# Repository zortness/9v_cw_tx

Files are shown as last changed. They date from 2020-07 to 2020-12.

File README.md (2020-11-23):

# 9V QRP Micro Transciever

Based on the schematic and work of Jeff Anderson, [K6JCA](https://www.qrz.com/db/k6jca)
and [this blog post](http://k6jca.blogspot.com/2009/08/9v-qrp-transceiver.html).

Thank you to Jeff for your help in debugging my implementation of your design.

## About

This is a very simple, direct conversion CW transciever that will operate on the 40m 
amateur radio band. It requires an external speaker or headphones, an external antenna,
and an external keyer for sending. 

This design is intended to allow modifying the center frequency of the transciever by
changing out the oscillator crystal without re-soldering any parts. 

**This is still a work in progress.**

I have devided up the functionality across two small PCBs and used a 8-pin jumper between them.
This gives a bit more room to spread out the components, and hopefully avoid unwanted interactions.
It should also give a bit larger ground plane, which should help with environmental sensitivity.

The transmitter has an observed harmonic transmission on 14m, which might necessitate an external 
band pass filter board at some point.

The power output in my experiements so far has been quite small, in the 50-100mW range. 

The effective receive and transmit frequencies can also be apart from one another by enough that
you may not hear someone responding directly on your transmit frequency. This seems to be worse
at either extreme of the VXO adjustment, but not verified by data yet.

## Schematics

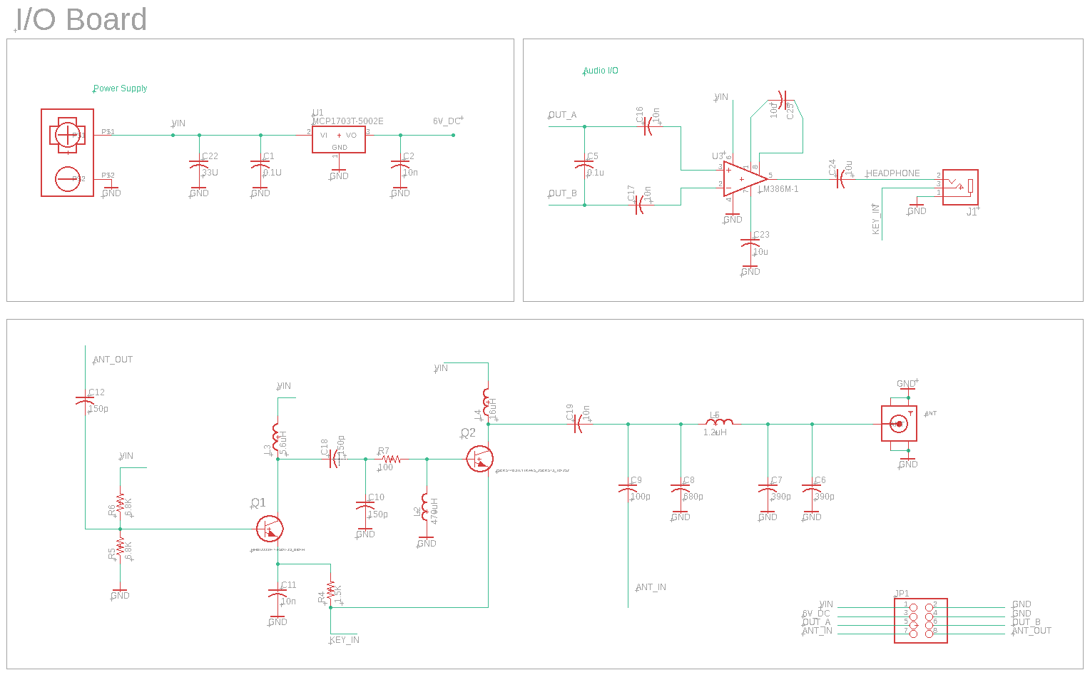
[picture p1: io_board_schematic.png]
IO board schematic


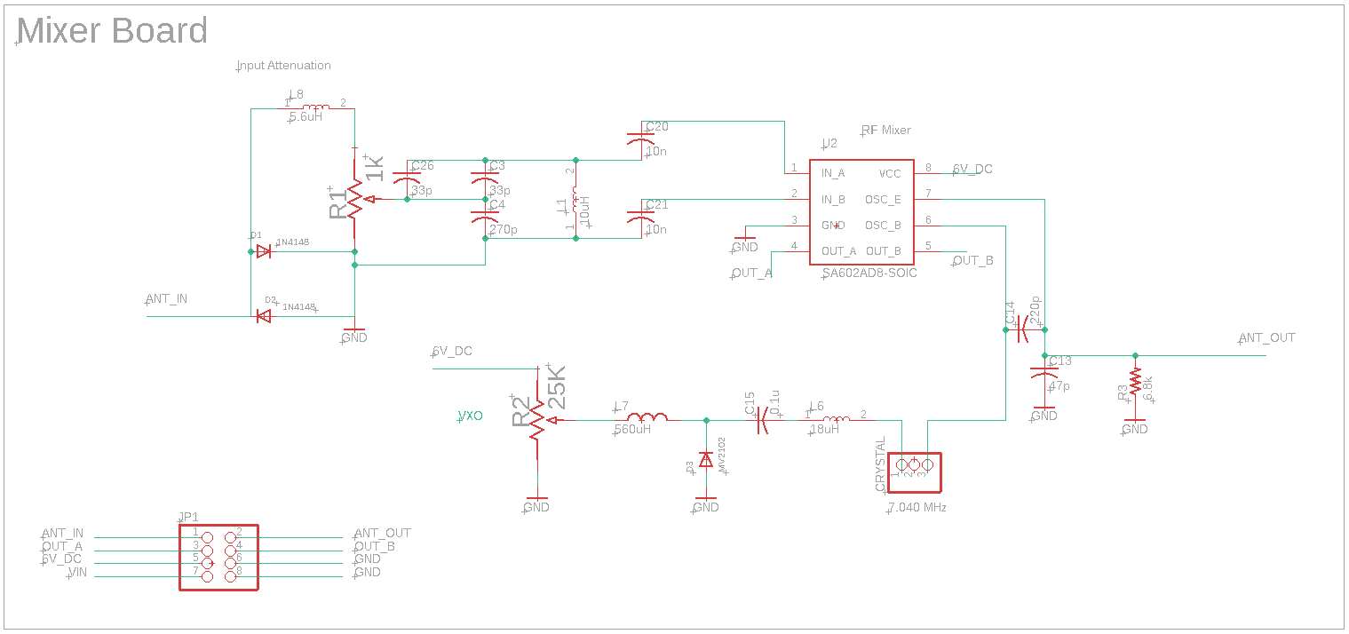
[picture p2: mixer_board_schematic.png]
Mixer board schematic


## Board Layouts

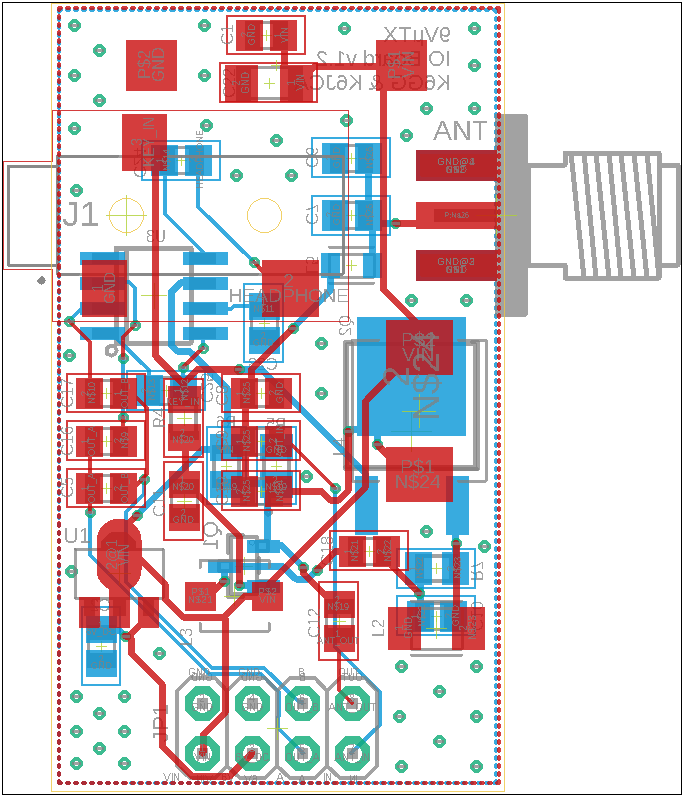
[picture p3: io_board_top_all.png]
IO board layout


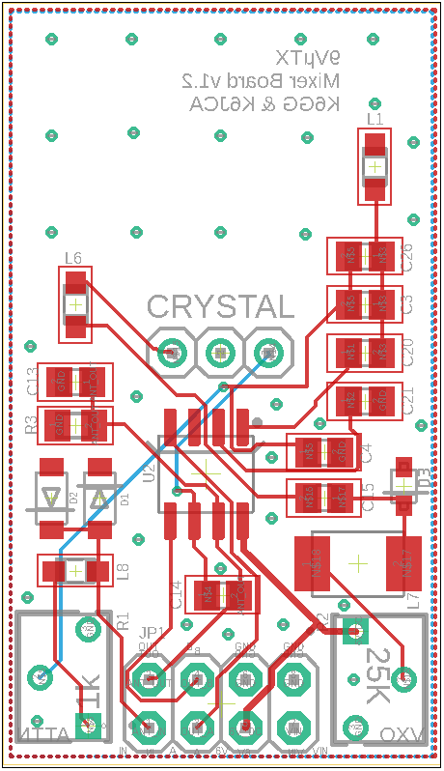
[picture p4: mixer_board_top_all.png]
Mixer board layout


## ProtoBoard Prototype 

This prototype is extremely sensitive to capacitance (even touch), and lacks a true ground plane,
though I added through-hole-pins to act as grounding feet on my steel work table. 

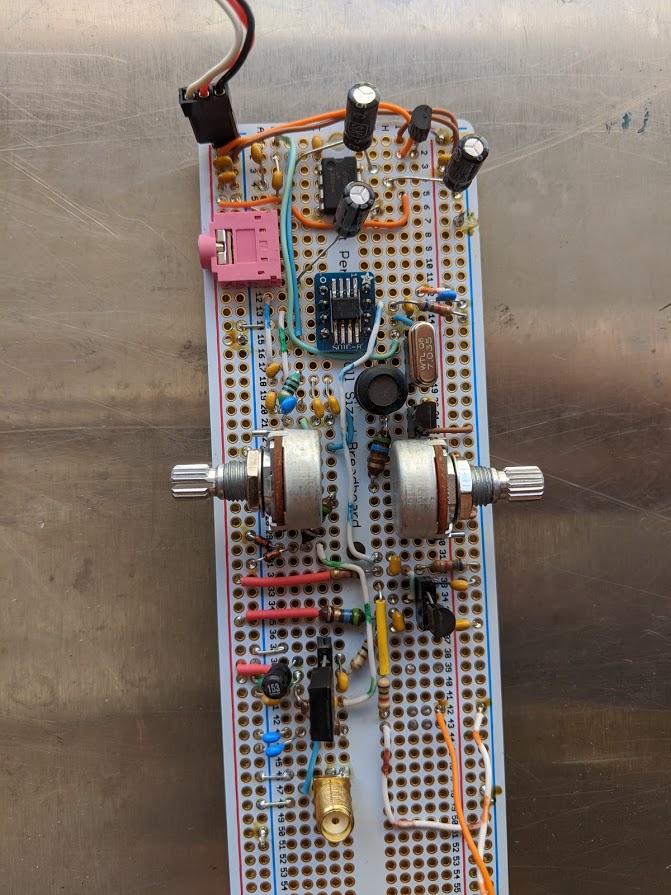
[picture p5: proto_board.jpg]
proto board


## SMD Prototypes

I've gone through a few SMD prototypes and made a number of pad and routing mistakes. I also chose
a number of parts poorly or just completely misread the units on the part values (nH != uH, pF != uF). 

I will update when one of the boards can operate without any further modification.

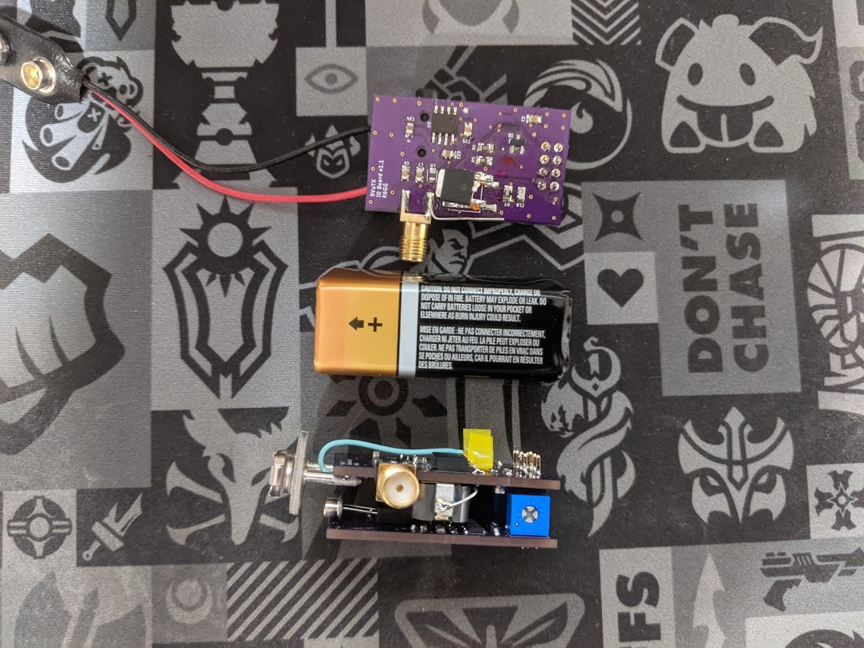
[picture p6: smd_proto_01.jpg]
proto board

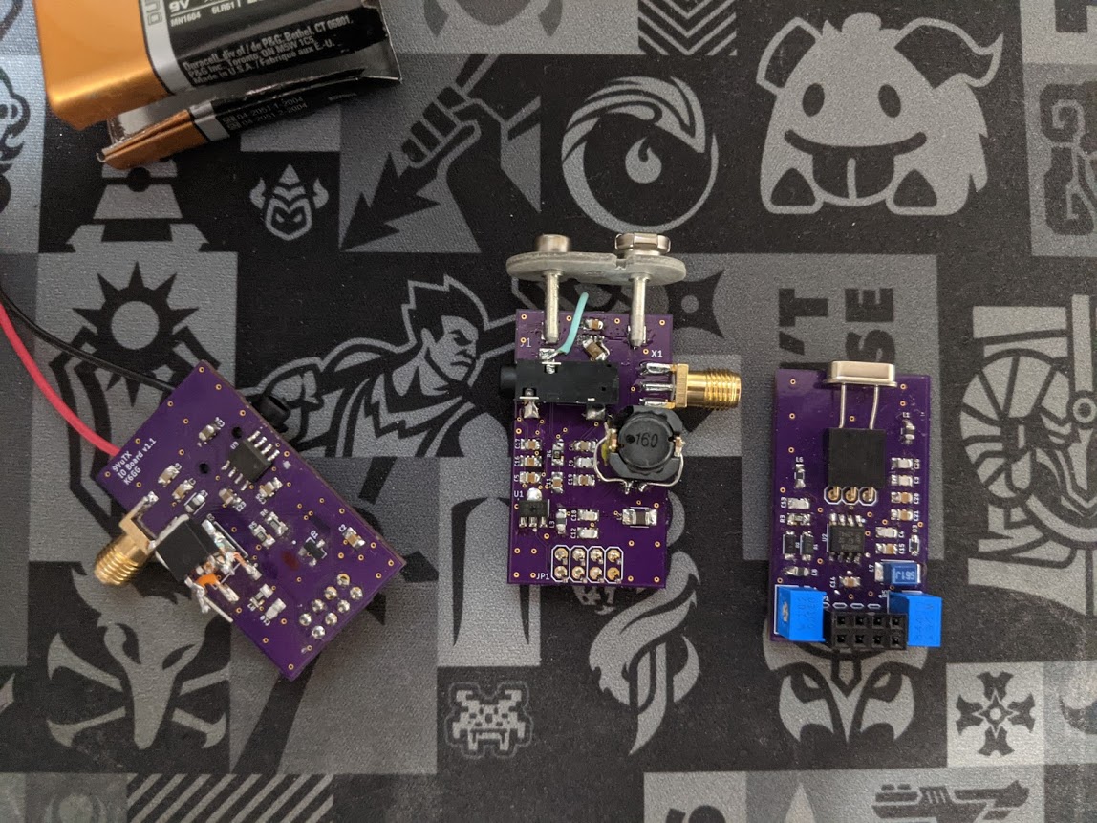
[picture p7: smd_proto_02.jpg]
proto board

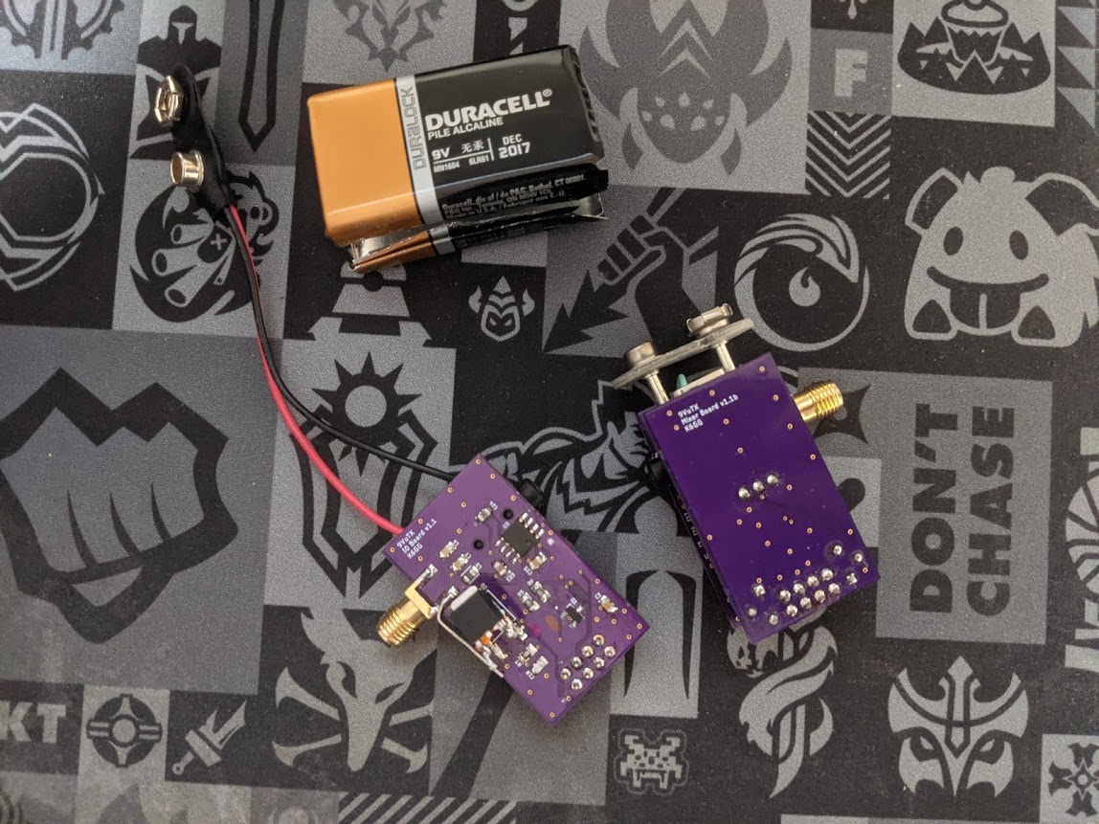
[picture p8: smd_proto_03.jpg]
proto board

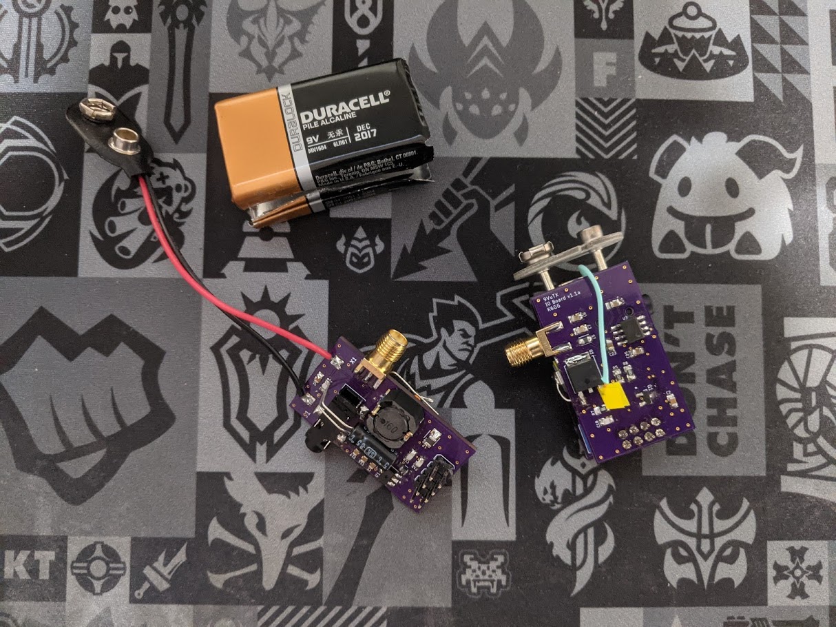
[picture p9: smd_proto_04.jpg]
proto board


## SMD BOM
|Manufacturer Part Number|Manufacturer |Digi-Key Part Number |Customer Reference |Reference Designator |Part Status|Quantity|Unit Price|Extended Price|
|---|---|---|---|---|---|---|---|---|
|MCP1703T-5002E/MB |Microchip Technology |MCP1703T-5002E/MBCT-ND |[U1] 5V regulator |U1 |Active |1 |0.54 |$0.54 |
|SA602AD/01,118 |NXP USA Inc. |568-1200-1-ND |[U2] RF Mixer |U2 |Active |1 |2.88 |$2.88 |
|LM386MX-1/NOPB |Texas Instruments |LM386MX-1/NOPBCT-ND |[U3] Audio Amp |U3 |Active |1 |1.02 |$1.02 |
|1N4148W-7-F |Diodes Incorporated |1N4148W-FDICT-ND |[D1,2] diode |D1, D2 |Active |2 |0.16 |$0.32 |
|1SV281(TPH3,F) |Toshiba Semiconductor and Storage|1SV281(TPH3F)CT-ND |[D3] varicap diode |D3 |Active |1 |0.36 |$0.36 |
|LBR2012T100K |Taiyo Yuden |587-2045-1-ND |[L1] inductor 10uH |L1 |Active |1 |0.13 |$0.13 |
|CB2518T471K |Taiyo Yuden |587-2194-1-ND |[L2] inductor 470uH |L2 |Active |1 |0.17 |$0.17 |
|MLF2012E5R6KT000 |TDK Corporation |445-1056-1-ND |[L8] inductor 5.6uH |L8 |Active |1 |0.18 |$0.18 |
|#B966AS-160M=P3 |Murata Electronics |490-14125-1-ND |[L4] inductor 16uH |L4 |Active |1 |0.95 |$0.95 |
|MLF2012A1R2JT000 |TDK Corporation |445-181331-1-ND |[L5] inductor 1.2uH |L5 |Active |1 |0.22 |$0.22 |
|MLF1608C180KTA00 |TDK Corporation |445-1028-1-ND |[L6] inductor 18uH |L6 |Active |1 |0.17 |$0.17 |
|NL453232T-561J-PF |TDK Corporation |445-NL453232T-561J-PFCT-ND|[L7] inductor 560uH |L7 |Active |1 |0.43 |$0.43 |
|3362W-1-102LF |Bourns Inc. |3362W-102LF-ND |[R1] potentiometer 1k |R1 |Active |1 |1.02 |$1.02 |
|3362W-1-253LF |Bourns Inc. |3362W-253LF-ND |[R2] potentiometer 25k |R2 |Active |1 |1.02 |$1.02 |
|CRG0805F6K8 |TE Connectivity Passive Product  |A126384CT-ND |[R3,5,6] resistor 6.8k |R3, R5, R6 |Active |3 |0.1 |$0.30 |
|CRGCQ0805F1K5 |TE Connectivity Passive Product  |A129751CT-ND |[R4] resistor 1.5k |R4 |Active |1 |0.1 |$0.10 |
|2SCR574D3TL1 |Rohm Semiconductor |2SCR574D3TL1CT-ND |[Q2] NPN transistor 2A |Q2 |Active |1 |0.82 |$0.82 |
|SJ-3502-SMT-TR |CUI Devices |CP-3502SJCT-ND |[J1] Audio Jack |J1 |Active |1 |1.22 |$1.22 |
|CON-SMA-EDGE-S |RF Solutions |CON-SMA-EDGE-S-ND |[J2] SMA-F edge connector |J2 |Active |1 |1.69 |$1.69 |
|PH2-20-UA |Adam Tech |2057-PH2-20-UA-ND |[JP1] Jumper Pins Male |JP1 |Active |1 |0.26 |$0.26 |
|PPPC042LFBN-RC |Sullins Connector Solutions |S7107-ND |[JP2] 8-pin Jumper Female |JP2 |Active |1 |0.69 |$0.69 |
|PPPC031LGBN-RC |Sullins Connector Solutions |S5478-ND |[J3] 3-pin Female Crystal Socket|J3 |Active |1 |0.51 |$0.51 |
|968 |Keystone Electronics |36-968-ND |[B1] 9V battery connector |B1 |Active |1 |1.48 |$1.48 |
|C0805C104Z5VACTU |KEMET |399-1177-1-ND |[C1,5,15] capacitor 0.1uF |C1, C5, C15 |Active |3 |0.1 |$0.30 |
|C0805C330K5GACTU |KEMET |399-8062-1-ND |[C3,22,26] capacitor 33pF |C3, C22, C26 |Active |3 |0.11 |$0.33 |
|CC0805JRNPO9BN271 |Yageo |311-1116-1-ND |[C4] capacitor 270pF |C4 |Active |1 |0.13 |$0.13 |
|CC0805KRX7R9BB391 |Yageo |311-1193-1-ND |[C6,7] capacitor 390pF |C6, C7 |Active |2 |0.12 |$0.24 |
|CC0805KRX7R9BB681 |Yageo |311-1126-1-ND |[C8] capacitor 680pF |C8 |Active |1 |0.11 |$0.11 |
|C0805C101JAGAC7800 |KEMET |399-15000-1-ND |[C9] capacitor 100pF |C9 |Active |1 |0.1 |$0.10 |
|C0805C151J5GACTU |KEMET |399-1125-1-ND |[C10,12,18] capacitor 150pF |C10, C12, C18 |Active |3 |0.1 |$0.30 |
|C0805C470K5GACTU |KEMET |399-8081-1-ND |[C13] capacitor 47pF |C13 |Active |1 |0.11 |$0.11 |
|C0805C221M5RACTU |KEMET |399-8039-1-ND |[C14] capacitor 220pF |C14 |Active |1 |0.1 |$0.10 |
|RC0805FR-07100RL |Yageo |311-100CRCT-ND |[R7] resistor 100 Ohm |R7 |Active |3 |0.1 |$0.30 |
|MMBT2222A-7-F |Diodes Incorporated |MMBT2222A-FDICT-ND |[Q1] NPN Transistor .6A |Q1 |Active |1 |0.13 |$0.13 |
|SJ-3523-SMT-TR |CUI Devices |CP-3523SJCT-ND |[J1] 3.5mm Stereo Phone Jack |J1 |Active |1 |0.93 |$0.93 |
|GRM21BR61E106KA73K |Murata Electronics |490-16824-1-ND |[C23,24,25] capacitor 10uF |C23, C24, C25 |Active |3 |0.23 |$0.69 |
|C3216X5R1C336M160AB |TDK Corporation |445-6002-1-ND |[C22] capacitor 33pF |C22 |Active |1 |1.03 |$1.03 |
|CL21B103KBANNNC |Samsung Electro-Mechanics |1276-1015-1-ND |[C2,11,16,17,19,20,21] capacitor 10nF|C2, C11, C16, C17, C19, C20, C21|Active |10 |0.045 |$0.45 |
|ASPI-0630LR-150M-T15 |Abracon LLC |ASPI-0630LR-150M-T15CT-ND |[L4] Inductor 15uH |L4 |Active |1 |0.87 |$0.87 |
|SRP3012C-5R6M |Bourns Inc. |118-SRP3012C-5R6MCT-ND |[L3] Inductor 5.6uH | |Active |1 |0.96 |$0.96 |

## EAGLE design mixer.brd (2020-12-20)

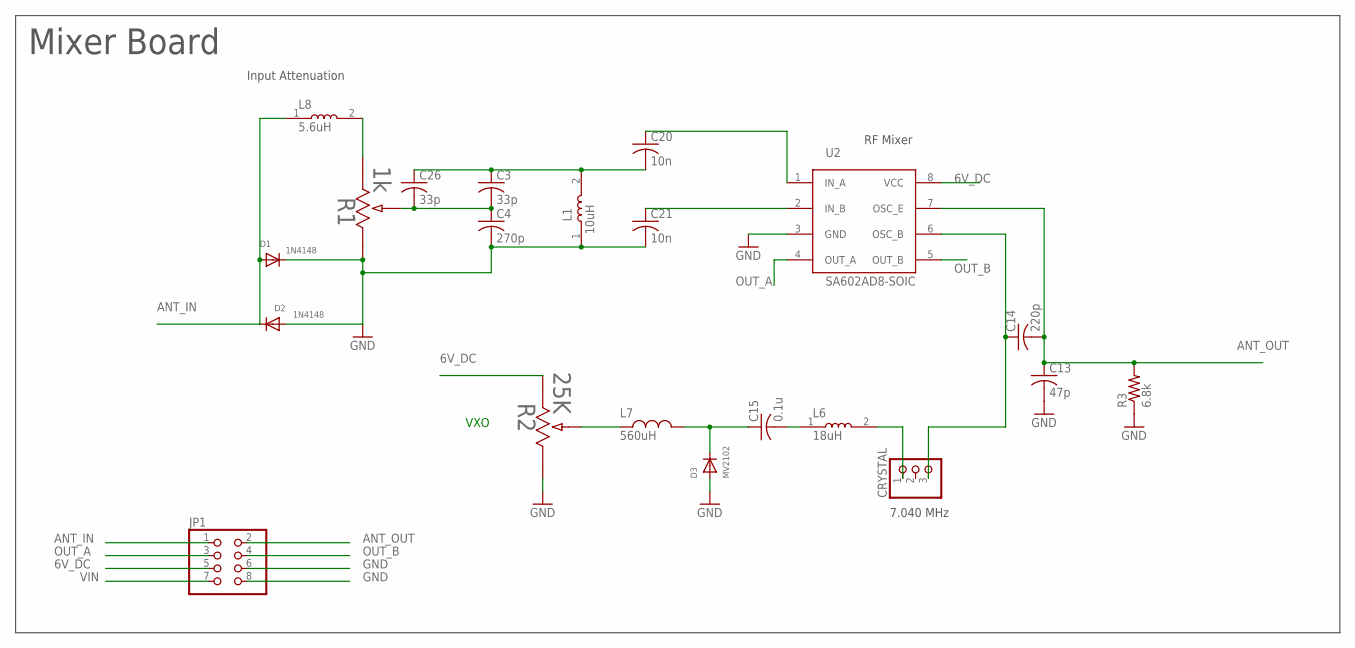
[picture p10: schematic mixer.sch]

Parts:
C3, C26: 33p; C0805
C4: 270p; C0805
C13: 47p; C0805
C14: 220p; C0805
C15: 0.1u; C0805
C20, C21: 10n; C0805
CRYSTAL: PINHD-1X3; 1X03
D1, D2: 1N4148; SOD-123FL
D3: MV2102; SOD-323F
JP1: PINHD-2X4; 2X04
L1: 10uH; INDC2012X87N
L6: 18uH; INDC2012X87N
L7: 560uH; INDM4532X32_W
L8: 5.6uH; INDC2012X87N
R1: 1k; POT_3362W
R2: 25K; POT_3362W
R3: 6.8k; M0805
U2: SA602AD8-SOIC; SOIC127P599X175-8N

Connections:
6V_DC: JP1.5, R2.1, U2.8 (VCC)
ANT_IN: D1.A, D2.C, JP1.1, L8.1
ANT_OUT: C13.1, C14.2, JP1.2, R3.2, U2.7 (OSC_E)
GND: C4.2, C13.2, C21.2, D1.C, D2.A, D3.A, JP1.6, JP1.8, L1.1, R1.3, R2.3, R3.1, U2.3 (GND)
unnamed: C20.1, U2.1 (IN_A)
unnamed: C21.1, U2.2 (IN_B)
unnamed: C3.1, C20.2, C26.1, L1.2
unnamed: C14.1, CRYSTAL.3, U2.6 (OSC_B)
unnamed: C3.2, C4.1, C26.2, R1.2
unnamed: L8.2, R1.1
unnamed: CRYSTAL.1, L6.2
unnamed: C15.2, L6.1
unnamed: C15.1, D3.C, L7.2
unnamed: L7.1, R2.2
OUT_A: JP1.3, U2.4 (OUT_A)
OUT_B: JP1.4, U2.5 (OUT_B)
VIN: JP1.7

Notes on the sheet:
Input Attenuation
RF Mixer
VXO
7.040 MHz
Mixer Board

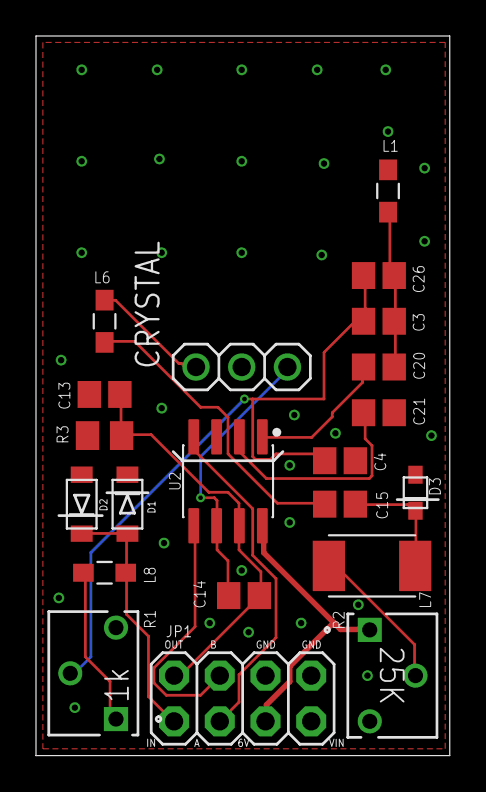
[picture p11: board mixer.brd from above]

Board: 2 copper layers, 23.0 x 40.0 mm, 21 parts (0 on the bottom side), 16 nets.

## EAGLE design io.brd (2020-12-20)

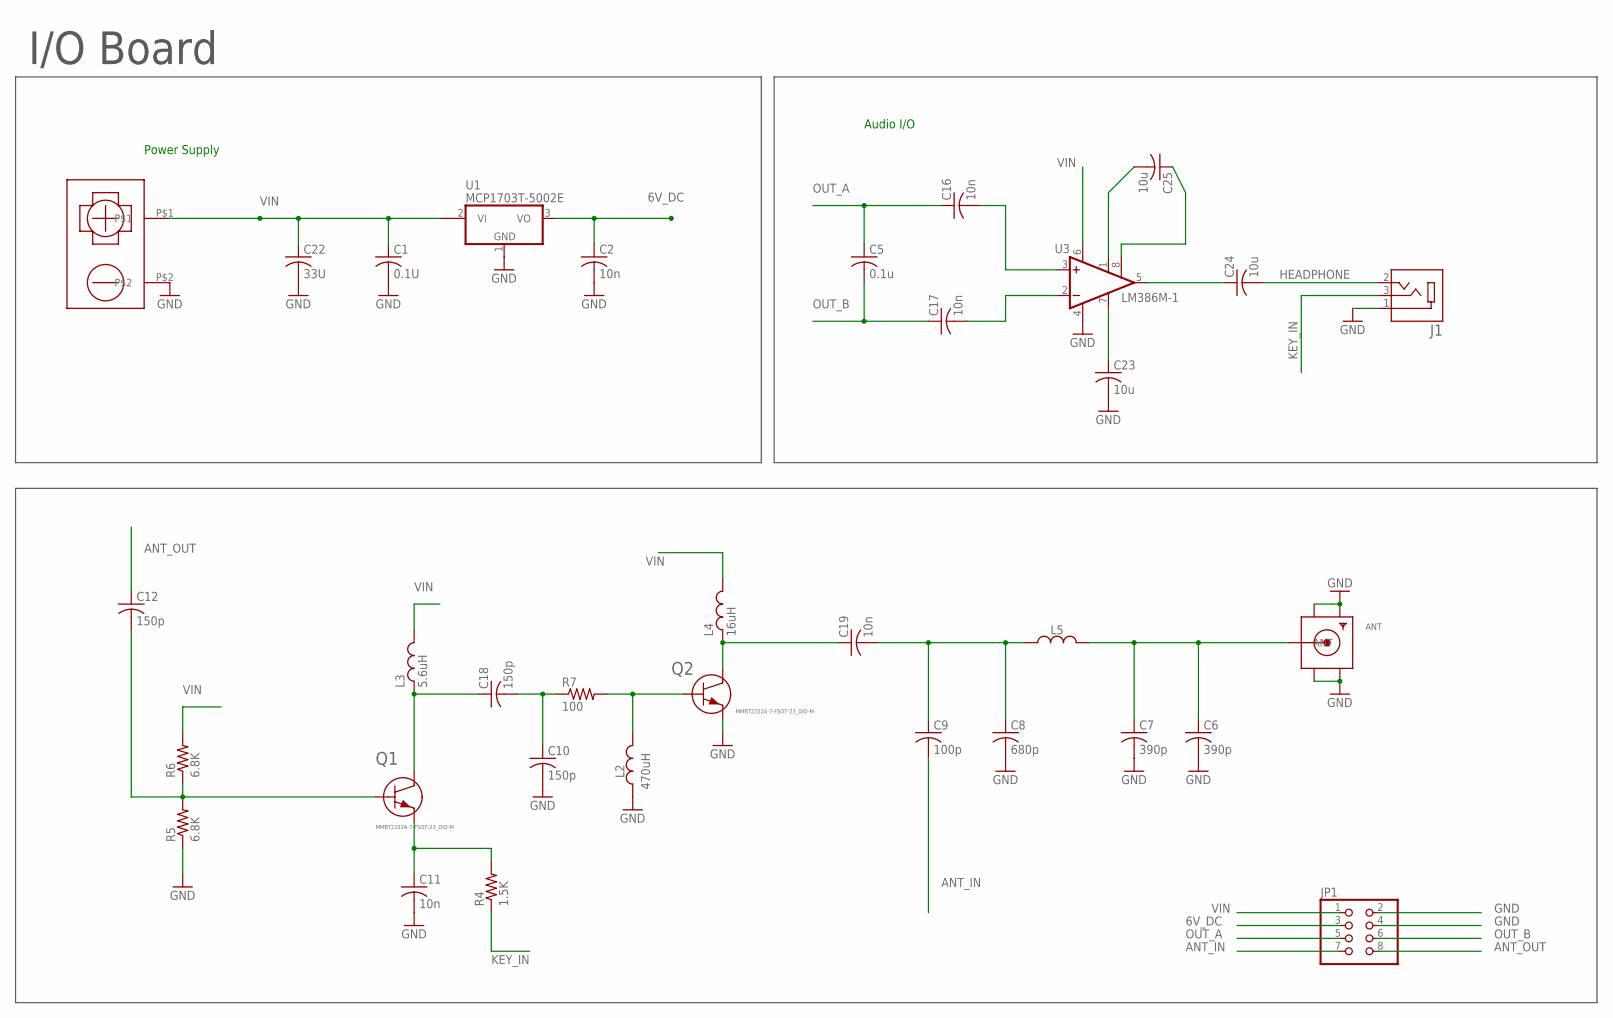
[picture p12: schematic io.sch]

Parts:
ANT: SMACONNECTOR_EDGE; SMA_EDGELAUNCH
C1: 0.1U; C0805
C2, C11, C16, C17: 10n; C0805
C5: 0.1u; C0805
C6, C7: 390p; C0805
C8: 680p; C0805
C9: 100p; C0805
C10, C12, C18: 150p; C0805
C19: 10n; C1206
C22: 33U; C1206
C23, C24, C25: 10u; C0805
J1: SJ-3523-SMT-TR; CUI_SJ-3523-SMT-TR
JP1: PINHD-2X4; 2X04
L2: 470uH; INDC2520X120N
L3: 5.6uH; SRP3012C
L4: 16uH; ASPI-0630LR
L5: 1.2uH; SRN4018TA
Q1, Q2: MMBT2222A-7-FSOT-23_DIO-M; SOT-23_DIO-M
R4: 1.5K; M0805
R5, R6: 6.8K; M0805
R7: 100; M0805
U1: MCP1703T-5002E; SOT89
U3: LM386M-1; SO08
U$1: 9V_9689V_968_SMD; 9V_968_PAD

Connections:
6V_DC: C2.1, JP1.3, U1.3 (VO)
ANT_IN: C9.2, JP1.7
ANT_OUT: C12.1, JP1.8
GND: ANT.GND@1 (GND4), ANT.GND@3 (GND2), C1.2, C2.2, C6.2, C7.2, C8.2, C10.2, C11.2, C22.2, C23.2, J1.1, JP1.2, JP1.4, L2.1, R5.1, U1.1 (GND), U3.4 (GND), U$1.P$2
HEADPHONE: C24.2, J1.2
KEY_IN: J1.3, R4.1
unnamed: C16.2, U3.3 (+IN)
unnamed: C17.2, U3.2 (-IN)
unnamed: C23.1, U3.7 (BYPASS)
unnamed: C25.1, U3.8 (GAIN)
unnamed: C25.2, U3.1 (GAIN)
unnamed: C24.1, U3.5 (OUT)
unnamed: C12.2, Q1.1, R5.2, R6.1
unnamed: C11.1, Q1.2 (3), R4.2
unnamed: C18.1, L3.P$1 (1), Q1.3 (2)
unnamed: C10.1, C18.2, R7.1
unnamed: L2.2, Q2.1, R7.2
unnamed: C19.1, L4.P$1 (1), Q2.3 (2)
unnamed: C8.1, C9.1, C19.2, L5.P$1 (1)
unnamed: ANT.P (ANT), C6.1, C7.1, L5.P$2 (2)
OUT_A: C5.1, C16.1, JP1.5
OUT_B: C5.2, C17.1, JP1.6
VIN: C1.1, C22.1, JP1.1, L3.P$2 (2), L4.P$2 (2), R6.2, U1.2@1 (VI1), U3.6 (VS), U$1.P$1

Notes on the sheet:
Power Supply
Audio I/O
I/O Board

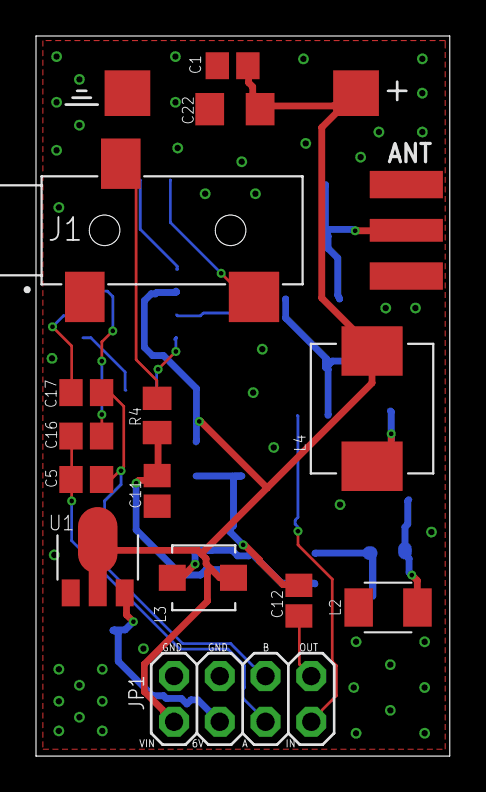
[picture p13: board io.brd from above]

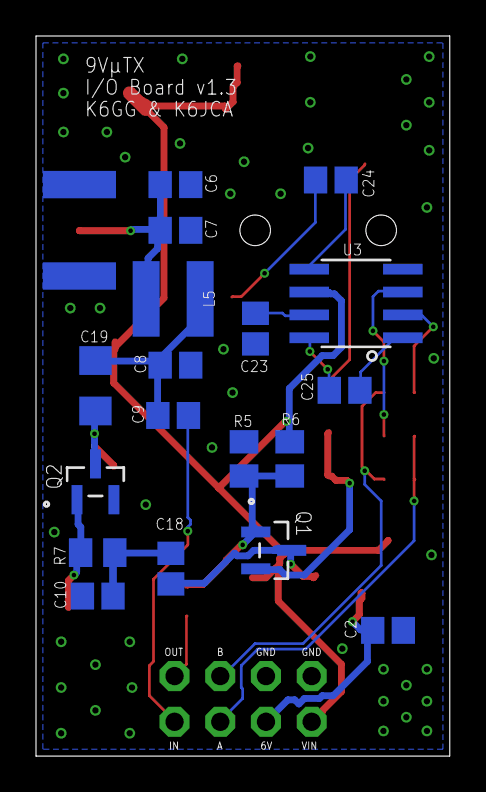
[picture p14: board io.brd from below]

Board: 2 copper layers, 23.0 x 40.0 mm, 34 parts (18 on the bottom side), 23 nets.

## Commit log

2020-05-26 initial commit
    An initial copy of K6JCA's CW transciever packaged in a 9V battery
    [main.brd, main.sch]
2020-05-27 first attempt at board layout
    [main.brd, main.sch]
2020-05-31 splitting boards, doing layouts
    Split into two boards with jumpers between. Added jumper for crystal to be able to change reference frequency. Closer to real layouts, still need to solidify some parts.
    [io.brd, io.sch, main.brd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]
2020-06-02 updating layouts and parts
    [io.brd, main.brd, mixer.brd]
2020-07-18 updated Q1, added readme
    Updated Q1 to be a better replacement for the original PN2222A in an SMD format. Also added a readme, with links to PNGs of the schematics and layout renderings, as well as a photo of one of my prototypes.
    [io.brd, io.sch]
2020-07-18 forgot to save mixer schematic
    Forgot to save while adjusting the schematic layout to make it more readable
    [mixer.sch]
2020-07-25 cleaned up boards, new screenshots
    Cleaned up the orientation and text on the boards. Ran them through the OshPark rules, and sent off v1 to get printed
    [io.brd, io.sch, mixer.brd]
2020-08-14 Updated boarts to v1.1
    9VuTX Version 1.1
    Several adjustments after mockup with V 1.0 of the board. That first version would be non-functional due to a few layout mismatches.
    * fixed 2nd transistor layout to actually match part / spec (TO-252)
    * rotated potentiometers 180 degrees so they face outward instead toward the middle of the board
    * expanded pads of L2 (450uH inductor) to match recommended spec
    * replaced phone jack with a true surface mount version (SJ-3523-SMT-TR)
    * re-arranged the IO board to allow for the different phone jack
    [io.brd, io.sch, mixer.brd]
2020-08-14 continuing on v 1.1
    * removed "label" label from SMA connector
    * increased the width of some lines likely to carry higher current
    * attempted to clean up some little stuff
    * updated images
    [io.brd, io.sch, main.brd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]
2020-08-18 Mixer board to 1.1a
    Realized the jumper on the Mixer board was not oriented correctly. Unfortunately already ordered some of the previous version, so this is a new version.
    [mixer.brd]
2020-08-18 Moving Mixer JP1 label
    [mixer.brd]
2020-09-01 Mixer board 1.1b
    * fixed pad size for L7
    [mixer.brd, mixer.sch]
2020-10-11 v1.1a of I/O board
    * Q2 pinout was wrong, pins 2 and 3 were swapped
    [io.brd, io.sch]
2020-10-16 Working on 1.1a of I/O after testing
    * replaced L4 with a much smaller component
    [io.brd, io.sch]
2020-10-17 Continuing on V1.1a of the I/O board
    * re-placed Q1 on the layout
    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
    [io.brd, io.sch, mixer.sch]
2020-10-17 Some cleanup
    * mixer board had incorrect Resistor labels
    * updated schematic PNG
    [mixer.brd, mixer.sch]
2020-11-21 v1.2 boards
    * corrected C22 as a 33uF (vs 33pF) capacitor with a 1206 footprint
    * Q2 emitter is now tied to Q1 emitter and KEY_IN to cut down on self resonance
    * Unused pin 4 on JP1 now tied to GND
    * All pins on JP1 labelled on top and bottom of each board
    * lots more GND vias
    [io.brd, io.sch, mixer.brd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]
2020-11-23 v1.2 updated inductors
    * updated L3 to a 650mA capable 5.6uH flat package
    * updated L4 to a 3A capable 15uH flat package... 16uH are difficult to come by
    * general board cleanup for readability
    [io.brd, io.sch, mixer.brd]
2020-11-23 Image updates
    * new boards and schematics
    * new photos of smd prototypes
2020-11-23 Update README to contain BOM
    Added a Bill of Materials (BOM) for the SMD prototype v1.2
2020-11-24 Version 1.2 as ordered
    * some slight cleanup in labels and routing after looking at the previews on oshpark
    [io.brd, mixer.brd]
2020-12-20 v1.3
    * replaced L5 and C19 with larger devices capable of more current
    * replaced Q2 with another 2222A
    * increased power and output wire size to 15mil (from 12)
    Revisions based on testing with my amplifier circuit breakout
    [io.brd, io.sch, mixer.brd]
